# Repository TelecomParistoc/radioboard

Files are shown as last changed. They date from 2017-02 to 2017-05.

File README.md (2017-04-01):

# RadioBoard

Design d'une carte électronique permettant de d'échanger des messages et de localiser les robots

## Définition des acteurs

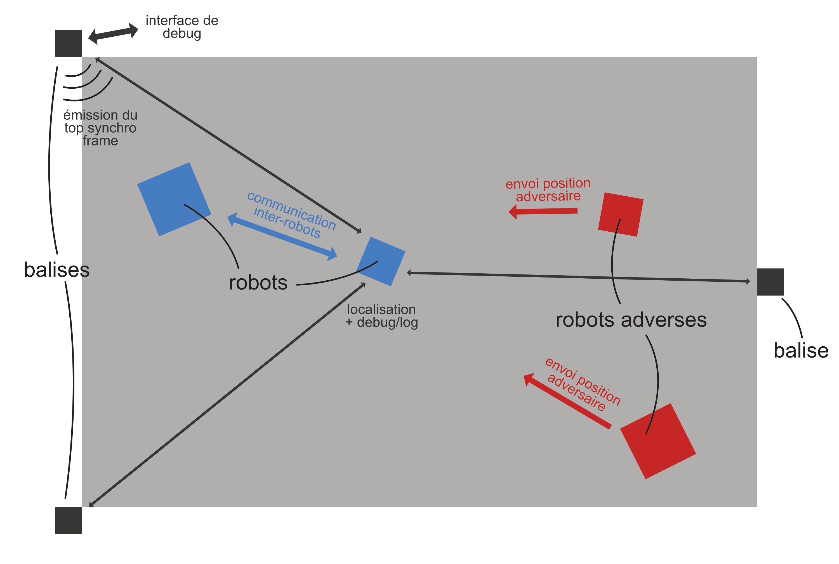
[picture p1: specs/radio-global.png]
radio global


On distingue 3 types d'acteurs aux besoins différents :

* les robots, où la radio se comporte comme un esclave piloté par le raspberry pi et autres composants
* les balise sur les robots adverses, où la radio est indépendante et doit envoyer les mesures aux robots
* les balises fixes, où la radio est indépendante et peut communiquer avec un ordinateur pour le debug

Pour des raisons d'efficacité, il a été décidé de ne concevoir qu'une seule carte, adaptée aux besoins de tous les acteurs.

## Vue système

### Système robot

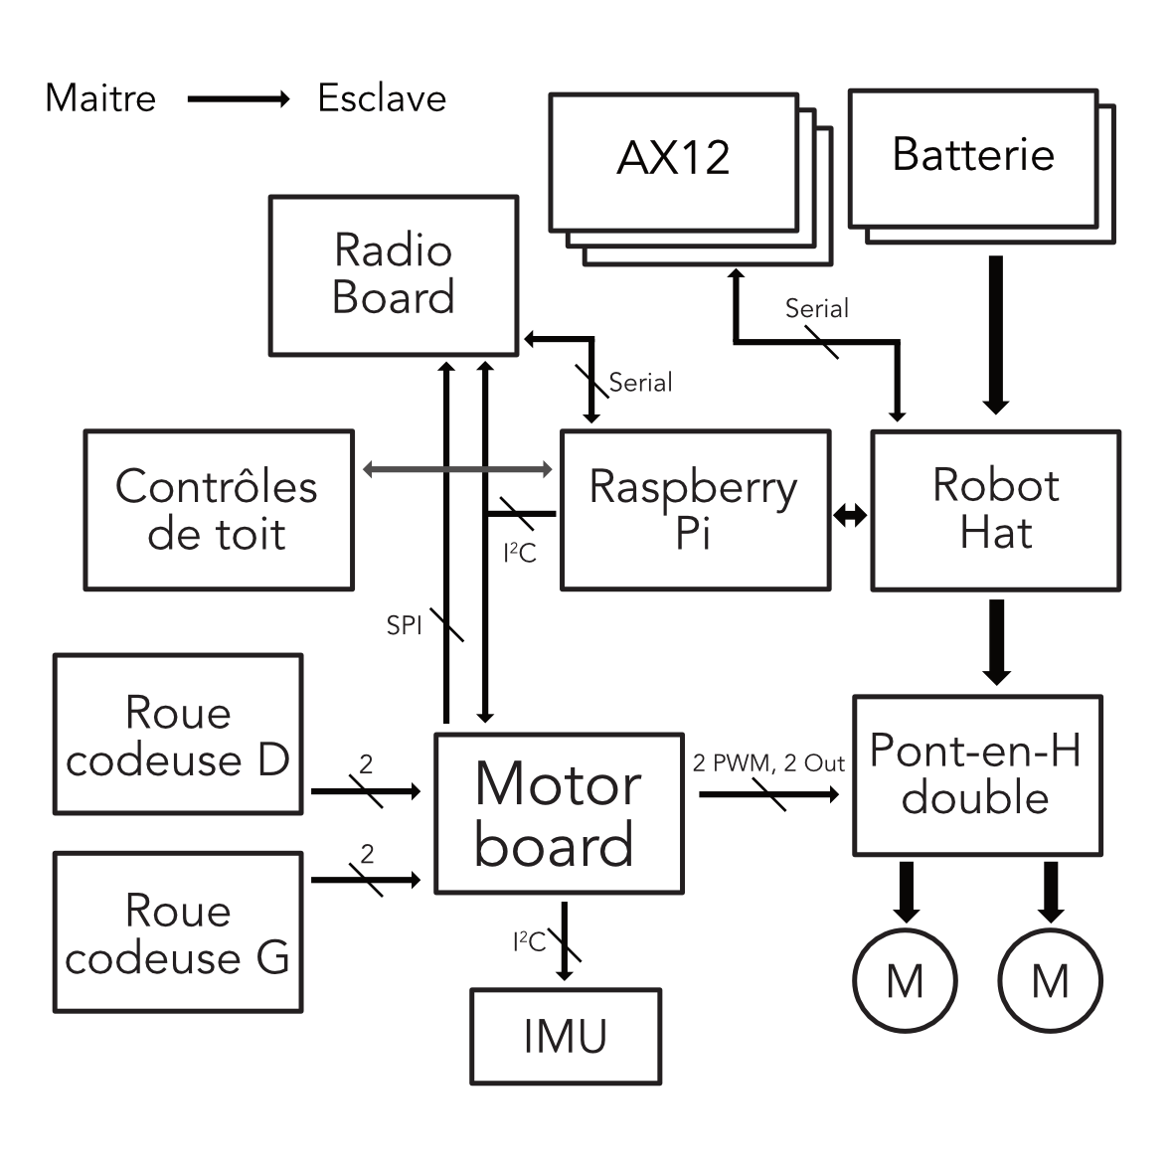
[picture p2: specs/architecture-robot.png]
archi robot


Il est nécessaire de fournir 3 ports :

* Un port esclave sur le bus I2C principal du robot, permettant la communication avec le Raspberry Pi
* Un port esclave SPI pour une liaison direct rapide à faible latence avec la carte de contrôle des moteurs
* Un port série pour ouvrir un terminal série à distance sur le Raspberry Pi contrôlé depuis une balise fixe en cas de perte de la connexion WiFi (environnement difficile pendant la coupe)

Par ailleurs, l'alimentation qui sera fournie à la carte sera du 5V (en raison de la consommation importante des Decawaves, il est plus raisonnable de ne pas tirer sur le 3.3V du Raspberry Pi), elle devra donc être abaissée localement.

### Système balise

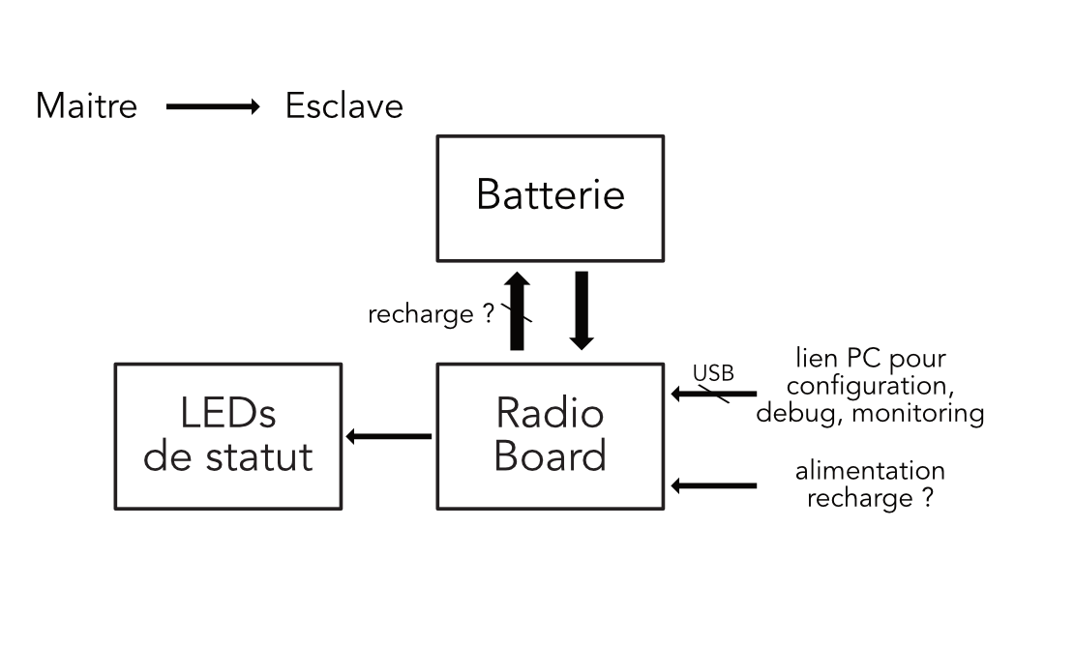
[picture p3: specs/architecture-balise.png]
archi balise


Dans les balises (fixes et sur les robots adverses), la carte radio est l'unique carte, et n'est accompagnée que d'une batterie. Elle doit donc être autonome.

La faisabilité d'un système interne de recharge doit être étudié. Dans tous les cas, le système doit pouvoir détecter la fin de décharge de la batterie afin d'éviter la destruction de celle-ci.

## Contraintes

#### RC1 Placement du module radio
Pour fonctionner correctement, le module radio DWM1000 doit être placé conformément aux contraintes de la datasheet du DWM1000 page 17.

#### RC2 Taille de la carte
Afin de pouvoir être embarqué dans les balises, la carte devra avoir des dimensions maximales de 70mmx70mm. De plus, il est important de minimiser la taille de la carte pour des raisons d'efficacité budgétaire. Il faut également prévoir le placement des batteries pour les balises, afin que le système total rentre dans un pavé de 80x80x80mm comme spécifié dans le règlement de la coupe de France de robotique.

#### RC3 Placement des connecteurs
Tout les connecteurs devront être placés de telle sorte qu'un câble connecté ne puisse pas se mettre dans le chemin du signal radio entre deux modules.

#### RC4 Programmation et debug de la carte
La programmation et le debug des cartes sera fait avec les sondes J-link du club en SWD et devra utiliser un connecteur comme [celui-ci](http://fr.farnell.com/samtec/shf-105-01-l-d-sm/embase-male-1-27mm-2x5-voies/dp/1885915).

#### RC5 Alimentation de la carte
L'alimentation de la carte se fera dans les robots en 5VDC et dans les balises directement depuis les batteries sans composant extérieur.

#### RC6 Technologie des batteries
Le règlement de la coupe de France de robotique interdit l'utilisation de batteries Li-Ion et Li-Po en dehors d'un sac de protection, dont les dimensions rendront l'intégration dans des balises difficile. Ces deux technologies sont donc exclues.

#### RC7 Configuration du connecteur I2C
Le connecteur I2C reliant la carte au bus principal et fournissant l'alimentation **5V** est un micromatch 6 pins et doit avoir la configuration suivante :
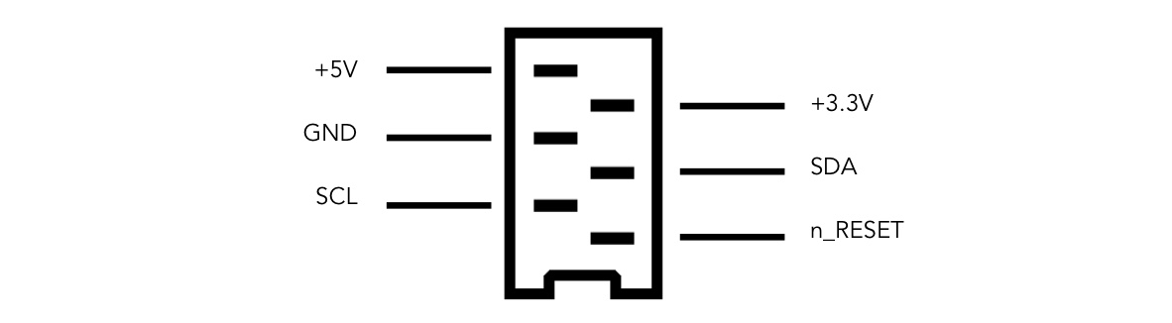
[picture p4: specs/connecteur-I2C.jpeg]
connecteur I2C


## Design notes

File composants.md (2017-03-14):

# Liste des composants

* STM32F302C8T6
* DWM1000
* Batterie GP210AAHCB-C4 (farnell) Nickel-hydrure métalique 1.2V(X4) AA 2000mAh
* connecteur de sonde SWD SAMTEC_SHF-105-01-L-D-SM
* leds de debugage (1 pour indiquer que la carte est sous alimentation et un pour le debugage)
* Connecteurs: 6 pins (SPI avec la motorbord, Serie avec RPI, I2C avec RPI et motorboard).
* 1 port microUSB

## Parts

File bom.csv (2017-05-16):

Qty | Qty to buy | Value | Device | Package | Parts | Description | Farnell reference
4 | 0 |  | LEDCHIPLED_0805 | CHIPLED_0805 | BATT ON RX/TX SYNC | LED | /
1 | 0 |  | SMDTOP-4 | SMDTOP4 | SERIAL | AMP connector | /
2 | 0 |  | SMDTOP-6 | SMDTOP6 | MOTSPI RPI | AMP connector | /
1 | 0 | 1.5k | R-US_M0805 | M0805 | R4 | RESISTOR | /
6 | 0 | 100n | C-EUC0805 | C0805 | C1 C2 C3 C6 C11 C13 | CAPACITOR | /
4 | 0 | 10u | C-EUC0805 | C0805 | C5 C9 C10 C12 | CAPACITOR | /
3 | 0 | 1k | R-US_M0805 | M0805 | R1 R2 R5 | RESISTOR | /
1 | 0 | 2.2k | R-US_M0805 | M0805 | R7 | RESISTOR | /
1 | 0 | 4.7u | C-EUC0805 | C0805 | C4 | CAPACITOR | /
2 | 0 | 47k | R-US_M0805 | M0805 | R3 R6 | RESISTOR | /
1 | 0 | 8MHz | CRYSTALSM49 | SM49 | Q1 | CRYSTAL | /
1 | 0 | DWM1000 | DWM1000 | DW1000-PACKAGE | DWM1000 |  | /
1 | 0 | STM32F302C8 | STM32F302_303C2 | LQFP48-7X7MM | U1 |  | /
1 | 0 | SWD/JTAG-_PINS | SWD/JTAG-_PINS | SAMTEC_SHF-105-01-L-D-SM | U$1 |  | /
1 | 0 | VREG-TS1117CW-3V3 | VREG-TS1117CW-3V3 | SOT223 | IC1 | Voltage Regulator | /
1 | 1 |  | USBMINIB | USB-MINIB | CN1 | USB Connectors | 2112367
2 | 2 | 18p | C-EUC0805 | C0805 | C7 C8 | CAPACITOR | 1759056

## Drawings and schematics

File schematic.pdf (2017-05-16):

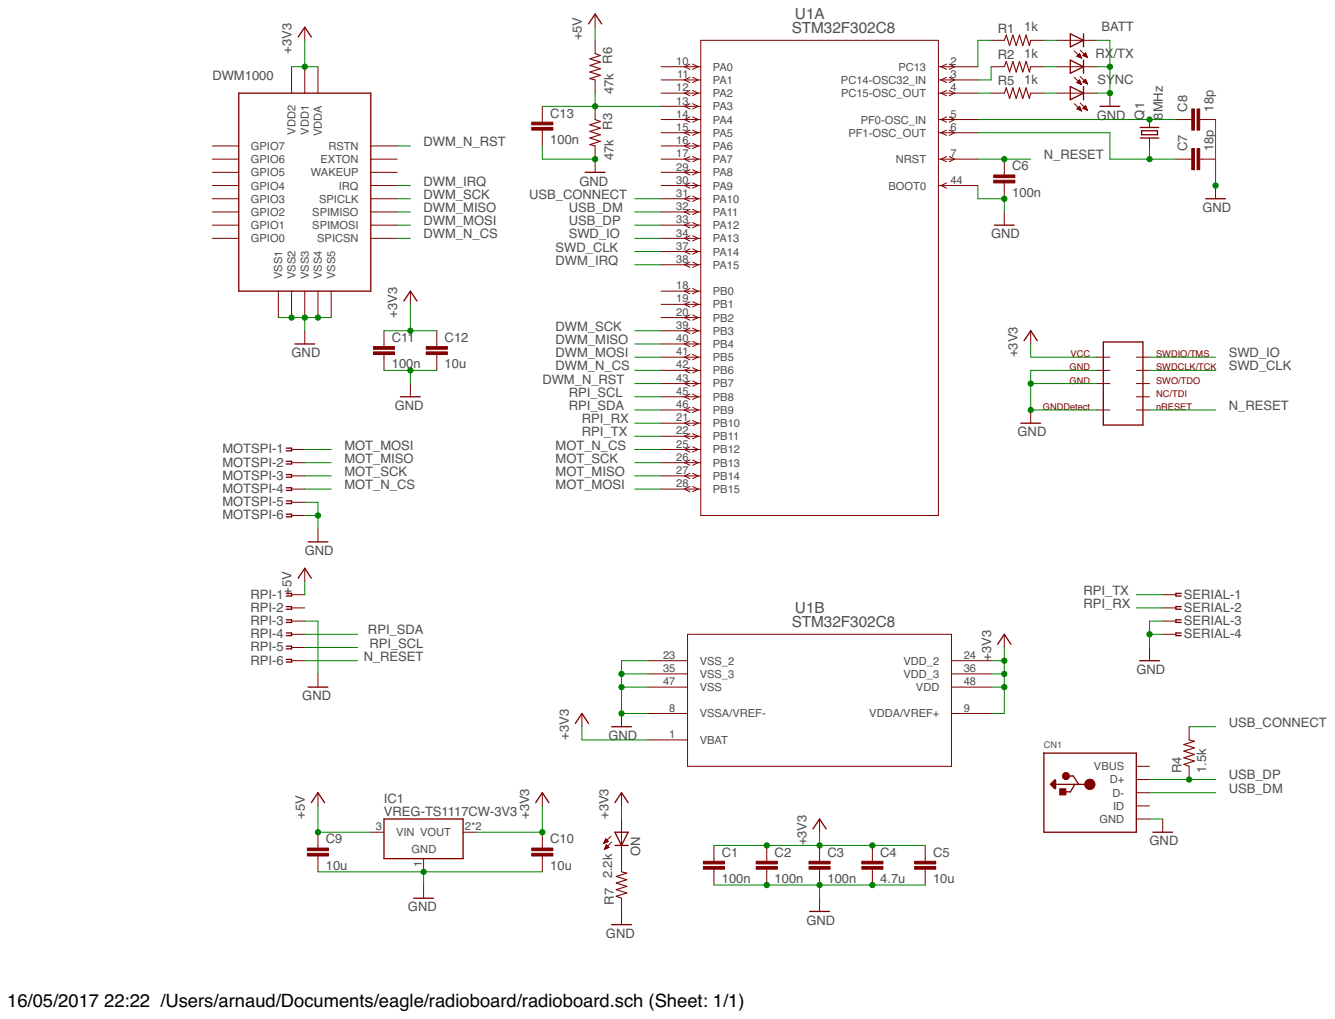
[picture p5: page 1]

VCC GND GND GNDDetect

16/05/2017 22:22 /Users/arnaud/Documents/eagle/radioboard/radioboard.sch (Sheet: 1/1)

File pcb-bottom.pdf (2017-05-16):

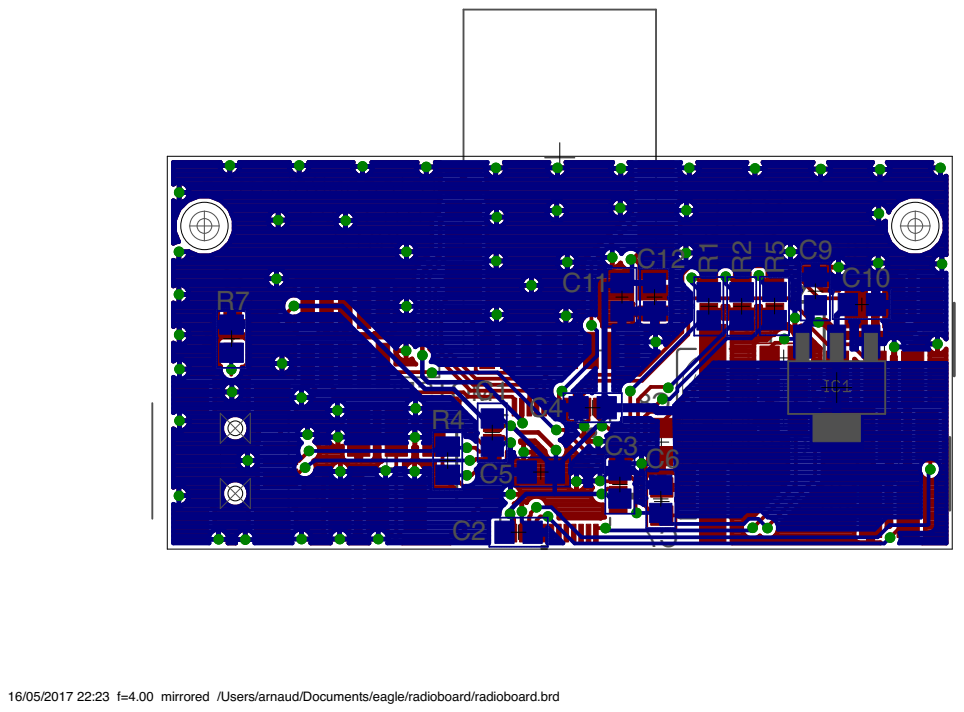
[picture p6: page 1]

16/05/2017 22:23 f=4.00 mirrored /Users/arnaud/Documents/eagle/radioboard/radioboard.brd

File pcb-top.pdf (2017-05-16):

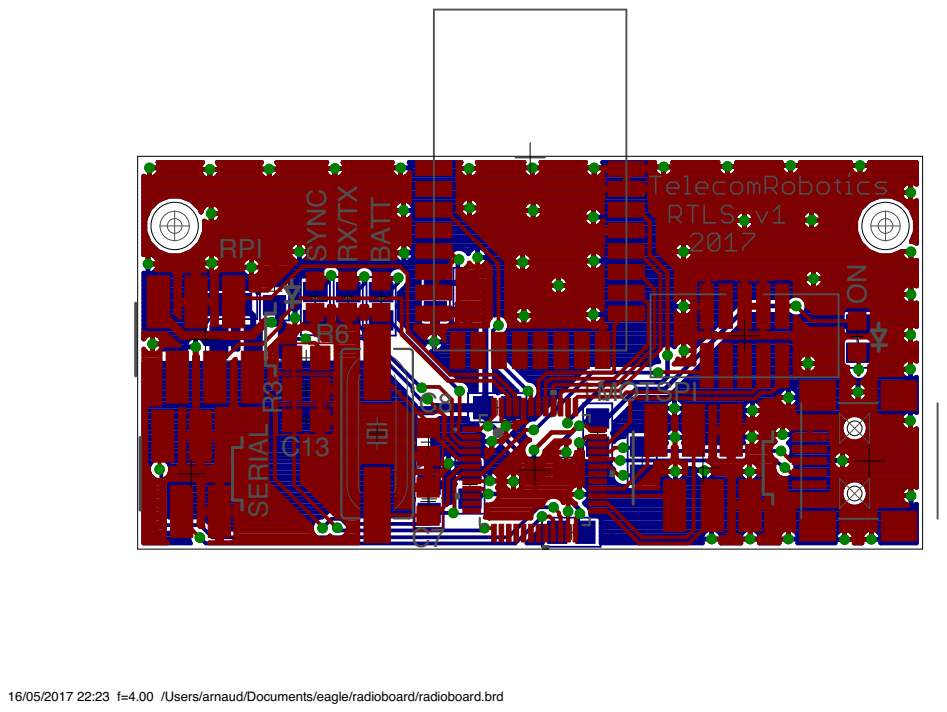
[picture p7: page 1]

16/05/2017 22:23 f=4.00 /Users/arnaud/Documents/eagle/radioboard/radioboard.brd

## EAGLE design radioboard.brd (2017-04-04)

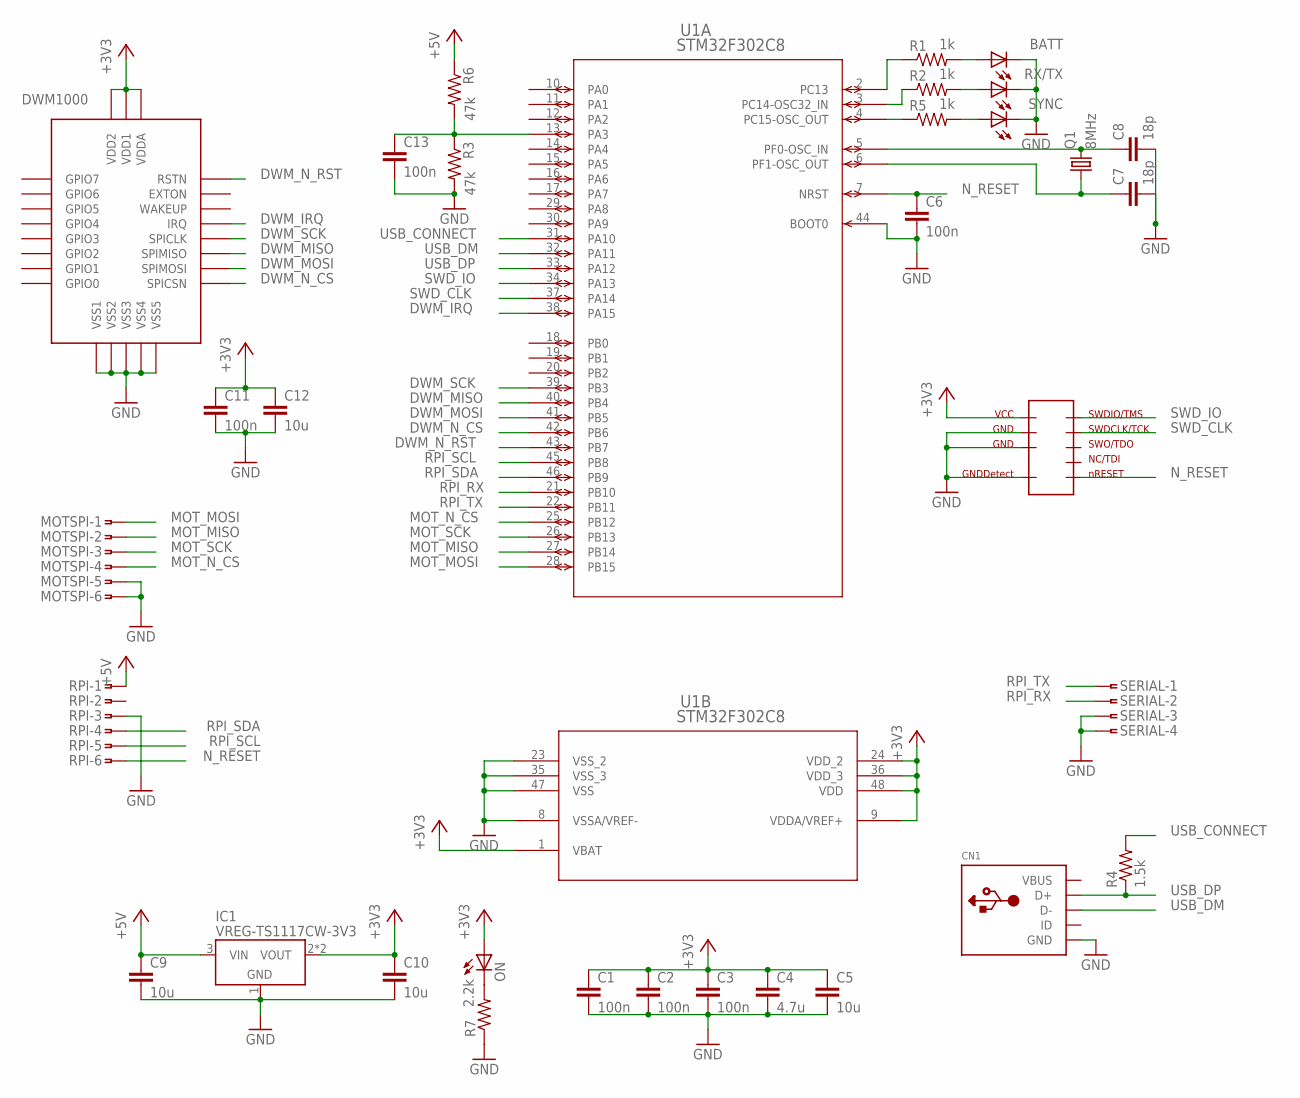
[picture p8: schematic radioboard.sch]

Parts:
BATT: LEDCHIPLED_0805; CHIPLED_0805
C1, C2, C3, C6, C11, C13: 100n; C0805
C4: 4.7u; C0805
C5, C9, C10, C12: 10u; C0805
C7, C8: 18p; C0805
CN1: USBMINIB; USB-MINIB
DWM1000: DWM1000; DW1000-PACKAGE
IC1: VREG-TS1117CW-3V3; SOT223
MOTSPI: SMDTOP-6; SMDTOP6
ON: LEDCHIPLED_0805; CHIPLED_0805
Q1: 8MHz; SM49
R1, R2, R5: 1k; M0805
R3, R6: 47k; M0805
R4: 1.5k; M0805
R7: 2.2k; M0805
RPI: SMDTOP-6; SMDTOP6
RX/TX: LEDCHIPLED_0805; CHIPLED_0805
SERIAL: SMDTOP-4; SMDTOP4
SYNC: LEDCHIPLED_0805; CHIPLED_0805
U1: STM32F302C8; LQFP48-7X7MM
U$1: SWD/JTAG-_PINS; SAMTEC_SHF-105-01-L-D-SM

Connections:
+3V3: C1.1, C2.1, C3.1, C4.1, C5.1, C10.1, C11.1, C12.1, DWM1000.VDD3V3 (VDD1), DWM1000.VDD3V32 (VDD2), DWM1000.VDDAON (VDDA), IC1.2 (VOUT), IC1.4 (VOUT), ON.A, U1.1 (VBAT), U1.9 (VDDA/VREF+), U1.24 (VDD_2), U1.36 (VDD_3), U1.48 (VDD), U$1.P$1
+5V: C9.1, IC1.3 (VIN), R6.1, RPI.1
DWM_IRQ: DWM1000.IRQ, U1.38 (PA15)
DWM_MISO: DWM1000.SPIMISO, U1.40 (PB4)
DWM_MOSI: DWM1000.SPIMOSI, U1.41 (PB5)
DWM_N_CS: DWM1000.SPICSN, U1.42 (PB6)
DWM_N_RST: DWM1000.RSTN, U1.43 (PB7)
DWM_SCK: DWM1000.SPICLK, U1.39 (PB3)
GND: BATT.C, C1.2, C2.2, C3.2, C4.2, C5.2, C6.2, C7.2, C8.2, C9.2, C10.2, C11.2, C12.2, C13.2, CN1.GND, DWM1000.VSS1, DWM1000.VSS2, DWM1000.VSS3, DWM1000.VSS4, DWM1000.VSS5, IC1.1 (GND), MOTSPI.5, MOTSPI.6, R3.2, R7.1, RPI.3, RX/TX.C, SERIAL.3, SERIAL.4, SYNC.C, U1.8 (VSSA/VREF-), U1.23 (VSS_2), U1.35 (VSS_3), U1.44 (BOOT0), U1.47 (VSS), U$1.P$3, U$1.P$5, U$1.P$9
MOT_MISO: MOTSPI.2, U1.27 (PB14)
MOT_MOSI: MOTSPI.1, U1.28 (PB15)
MOT_N_CS: MOTSPI.4, U1.25 (PB12)
MOT_SCK: MOTSPI.3, U1.26 (PB13)
unnamed: R1.1, U1.2 (PC13)
unnamed: C7.1, Q1.1, U1.6 (PF1-OSC_OUT)
unnamed: C8.1, Q1.2, U1.5 (PF0-OSC_IN)
unnamed: R2.1, U1.3 (PC14-OSC32_IN)
unnamed: R5.1, U1.4 (PC15-OSC_OUT)
unnamed: BATT.A, R1.2
unnamed: R2.2, RX/TX.A
unnamed: C13.1, R3.1, R6.2, U1.13 (PA3)
unnamed: ON.C, R7.2
unnamed: R5.2, SYNC.A
N_RESET: C6.1, RPI.6, U1.7 (NRST), U$1.P$10
RPI_RX: SERIAL.2, U1.21 (PB10)
RPI_SCL: RPI.5, U1.45 (PB8)
RPI_SDA: RPI.4, U1.46 (PB9)
RPI_TX: SERIAL.1, U1.22 (PB11)
SWD_CLK: U1.37 (PA14), U$1.P$4
SWD_IO: U1.34 (PA13), U$1.P$2
USB_CONNECT: R4.2, U1.31 (PA10)
USB_DM: CN1.D-, U1.32 (PA11)
USB_DP: CN1.D+, R4.1, U1.33 (PA12)
VBUS: CN1.VBUS

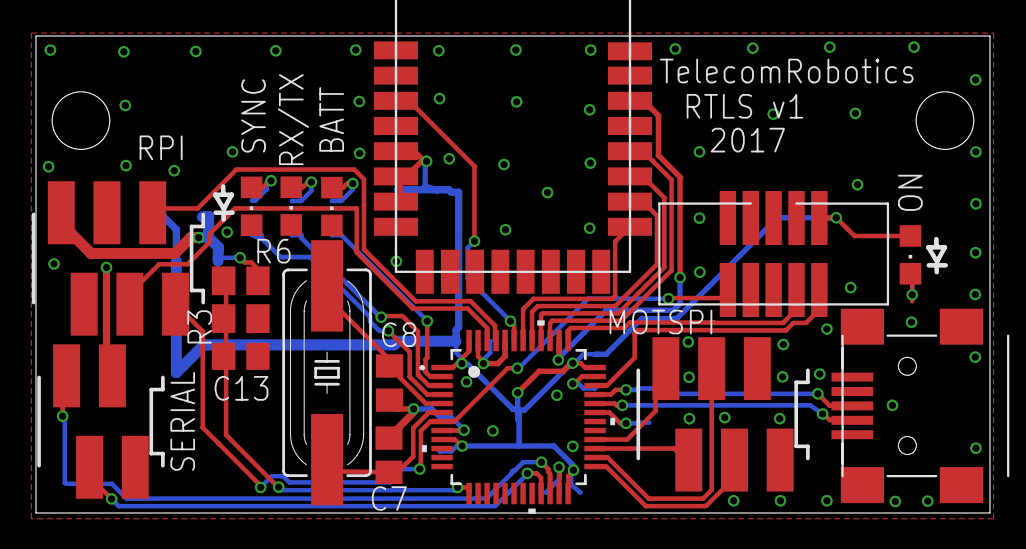
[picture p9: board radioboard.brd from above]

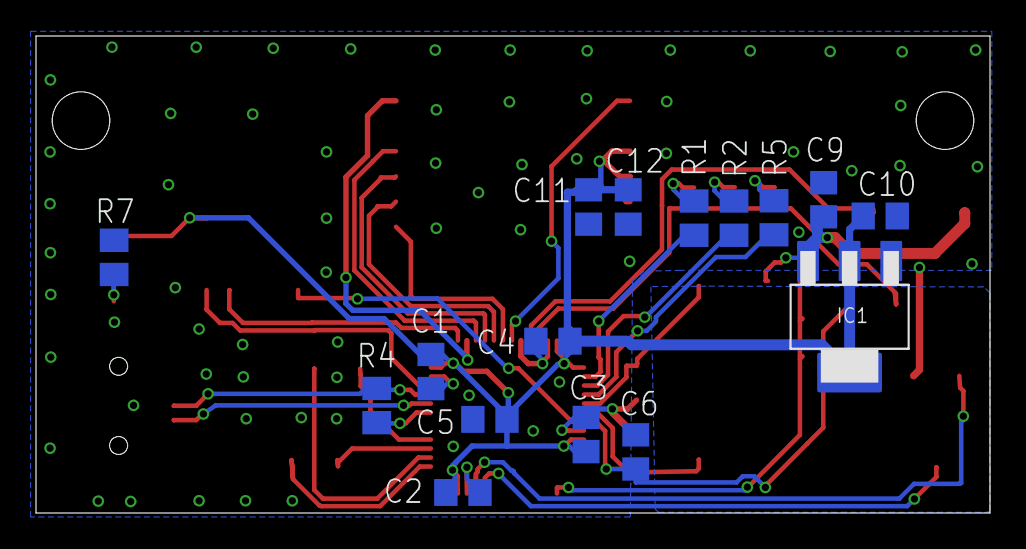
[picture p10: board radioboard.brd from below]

Board: 2 copper layers, 53.0 x 26.5 mm, 33 parts (16 on the bottom side), 33 nets.

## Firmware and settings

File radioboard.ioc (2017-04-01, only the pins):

Mcu.UserName=STM32F302C8Tx
PA10.GPIO_Label=USB_CONNECT
PA10.Signal=GPIO_Output
PA11.Signal=USB_DM
PA12.Signal=USB_DP
PA13.Signal=SYS_JTMS-SWDIO
PA14.Signal=SYS_JTCK-SWCLK
PA15.GPIO_Label=DWM_IRQ
PA15.Signal=GPIO_Output
PA3.GPIO_Label=VBAT_PROBE
PA3.Signal=ADC1_IN4
PB10.Signal=USART3_TX
PB11.Signal=USART3_RX
PB12.Signal=SPI2_NSS
PB13.Signal=SPI2_SCK
PB14.Signal=SPI2_MISO
PB15.Signal=SPI2_MOSI
PB3.Signal=SPI3_SCK
PB4.Signal=SPI3_MISO
PB5.Signal=SPI3_MOSI
PB6.GPIO_Label=SPI3_nCS
PB6.Signal=GPIO_Input
PB7.GPIO_Label=DWM_RST
PB7.Signal=GPIO_Output
PB8.Signal=I2C1_SCL
PB9.Signal=I2C1_SDA
PC13.GPIO_Label=STAT3
PC13.Signal=GPIO_Output
PF0-OSC_IN.Signal=RCC_OSC_IN
PF1-OSC_OUT.Signal=RCC_OSC_OUT

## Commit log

2017-02-26 battery technologies
2017-03-04 added I2C connector drawing
2017-03-04 smaller I2C connector
2017-03-04 upper case mess
2017-04-01 started schematic and board
    [radioboard.brd, radioboard.sch]
2017-04-01 added 3.3V LDO regulator datasheet
2017-04-01 finished schematic, continued placing
    [radioboard.brd, radioboard.sch]
2017-04-03 placed and routed PCB, added design rules
    [radioboard.brd]
2017-04-04 finished PCB
    [radioboard.brd, radioboard.sch]
2017-04-04 added pdf of board and schematic
    [radioboard.brd]
2017-05-16 added bom
    [bom.csv]

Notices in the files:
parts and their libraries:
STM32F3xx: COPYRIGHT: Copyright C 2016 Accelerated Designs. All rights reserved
